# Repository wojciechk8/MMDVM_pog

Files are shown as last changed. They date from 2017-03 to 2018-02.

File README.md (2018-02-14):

This project is a hardware for the Multi-Mode Digital Voice Modem
([MMDVM](https://github.com/g4klx/MMDVM)). Instead of depending on
MCU development boards (like Arduino, STM Discovery, etc.), this design
contains a microcontroller itself, so no additional stuff is required.
This project is based on [SQ6POG](https://www.qrz.com/db/SQ6POG)'s idea,
and hence its name.

## Hardware 
The board contains STM32F105RBT MCU, two active low-pass filters: for
ADC and DAC. Additionally there is a place for an optional TCXO with
a buffer circuitry and LED indicators.

The PCB is prepared to be populated in two configurations listed below.
### Stand-alone
The board is populated with FT230XS USB-to-UART converter and 3.3V LDO

### As a Raspberry Pi HAT
This configuration is almost the same as previous, but with RPi
connector and without USB-to-UART converter and LDO.

## Building firmware
You can get the firmware from [MMDVM](https://github.com/g4klx/MMDVM)
github. The firmware can be built with the GNU ARM toolchain.
An additional requirement is the STM32CubeF1 package, which can be found
at STMicroelectronics website. Path to the CMSIS directory of
the extrected package should be adjusted in the Makefile.CMSIS as
CMSISDIR definition. Also uncomment these defines in the Config.h
file:
```
// For the SQ6POG board
#define STM32F1_POG
```
to enable MMDVM_pog board support,
```
// Pass RSSI information to the host
#define SEND_RSSI_DATA
```
to enable RSSI feature,
```
// Use pins to output the current mode
#define ARDUINO_MODE_PINS
```
to enable mode LEDs output,
```
// For 19.2 MHz
#define EXTERNAL_OSC 19200000
```
if you want to use external TCXO.

Be sure that defines regarding other boards are commented.

Finally to build the firmware simply run:
```
make -f Makefile.CMSIS
```

## Programming
### Via SWD
To program the device with SWD, run:
```
make -f Makefile.CMSIS program
```
(you will need *openocd* software and ST-LINK programmer).

### Via internal bootloader
If you don't have ST-LINK and want to use bootloader, then short JP1
jumper and run:
```
make -f Makefile.CMSIS program_bl
```
(you will need *stm32flash* software; serial port can be selected
in the Makefile)

## Hacking
### Schematic/PCB
This project was designed using *gEDA* software. In order to modify
the schematic you will need my library of symbols/footprints, which is
available [here](https://github.com/wojciechk8/geda-sym). The library
is also attached to this repository as a submodule (geda-sym). To get it
contents after cloning the repository run `git submodule update --init`.
Update of the PCB is done in the root directory with this command:
```
gsch2pcb mmdvm_pog.prj
```
Postscript and pdf export of PCB is done with:
```
./pcb_export mmdvm_pog.pcb
```

### Filter simulation
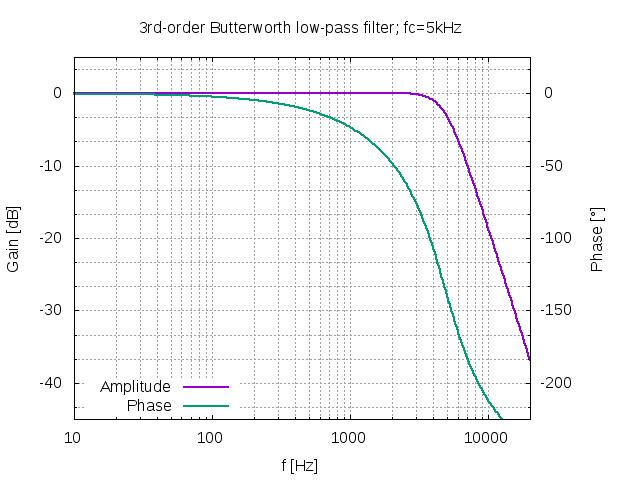
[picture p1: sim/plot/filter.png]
Filter frequency response simulation


The simulation of the filter (sim directory) was performed in *ngspice*
and the graphical plot output was generated using *gnuplot*. To run
the simulation use the script provided:
```
./simulate filter.sch
```

## License
This project is licensed under the CC-BY-NC-SA
(Creative Commons - Attribution, Noncommercial, Share Alike) license
and is intended for amateur and educational use only.

<p align="center">CC-BY-NC-SA</p>

MMDVM software is licenced under the GPL v2 and is intended for amateur
and educational use only. Use of this software for commercial purposes
is strictly forbidden.

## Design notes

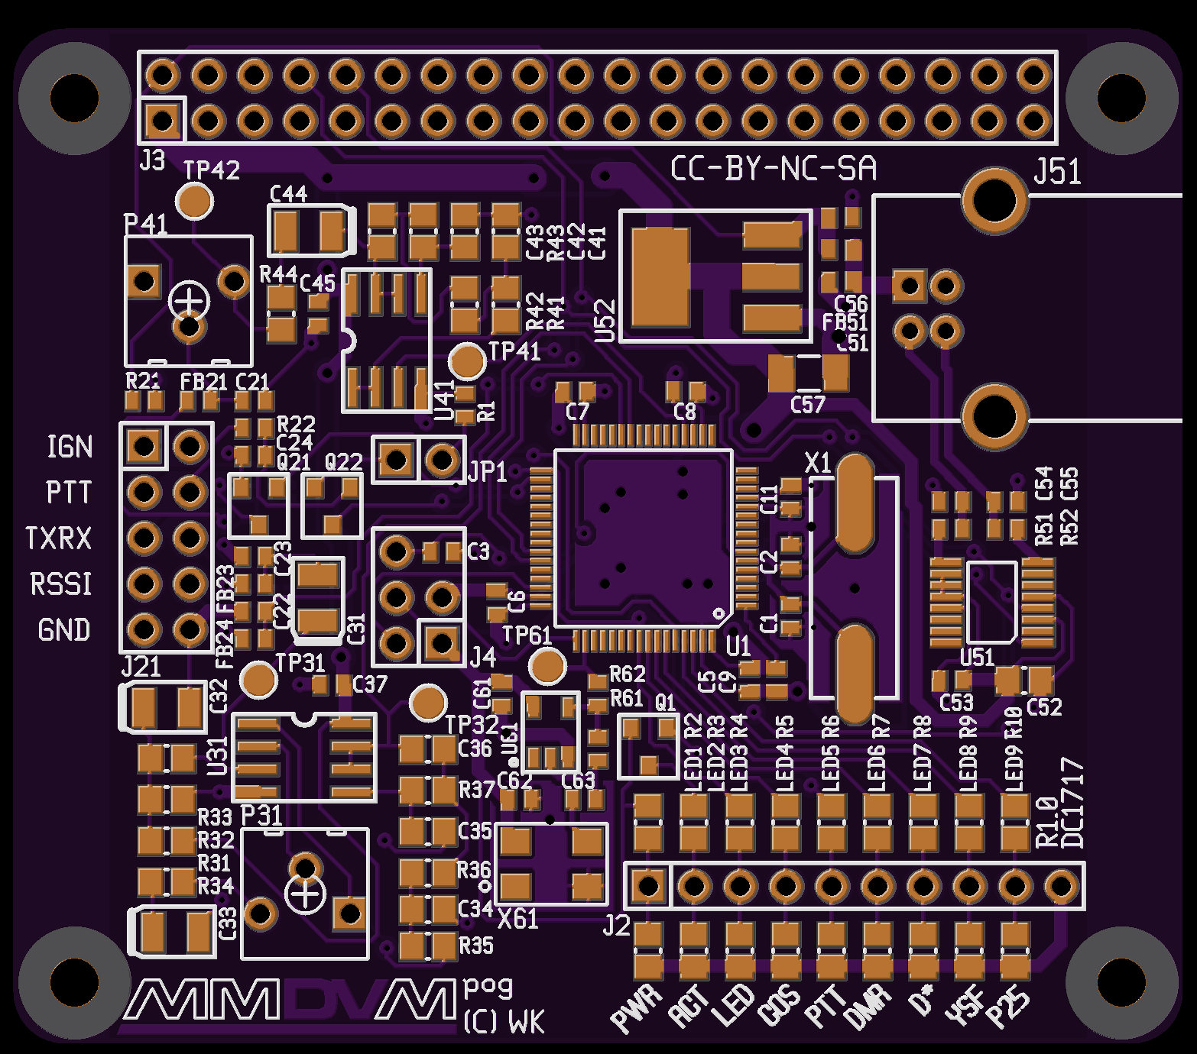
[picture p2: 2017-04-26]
pcb/mmdvm_pog.png

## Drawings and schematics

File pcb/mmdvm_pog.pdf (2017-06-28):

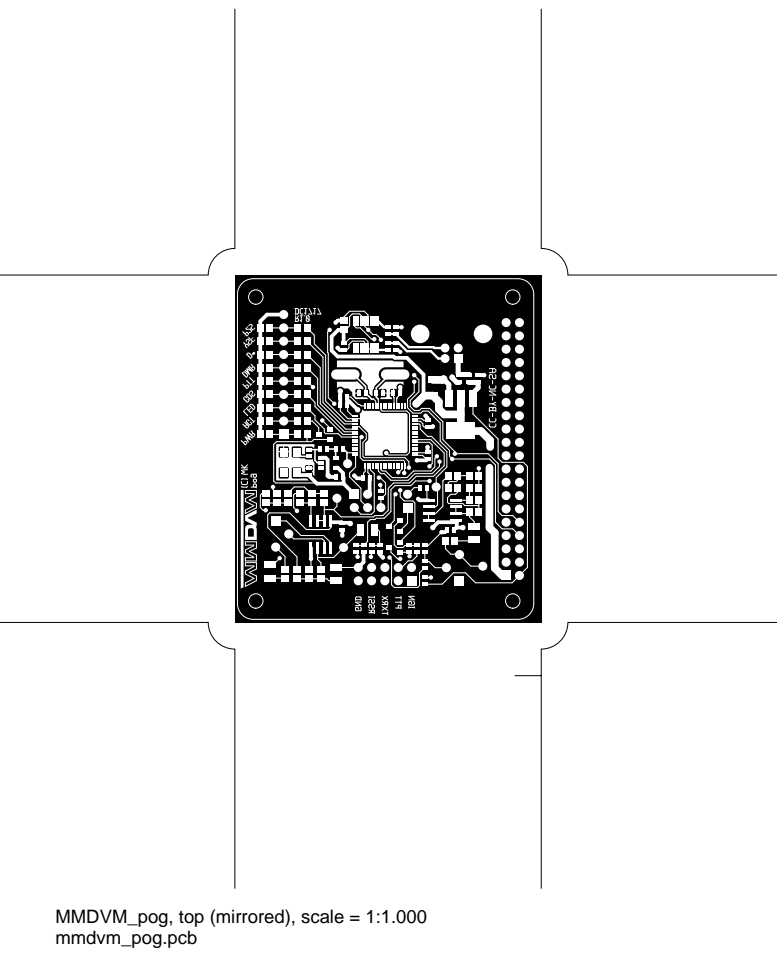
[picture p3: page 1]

MMDVM_pog, top (mirrored), scale = 1:1.000
mmdvm_pog.pcb

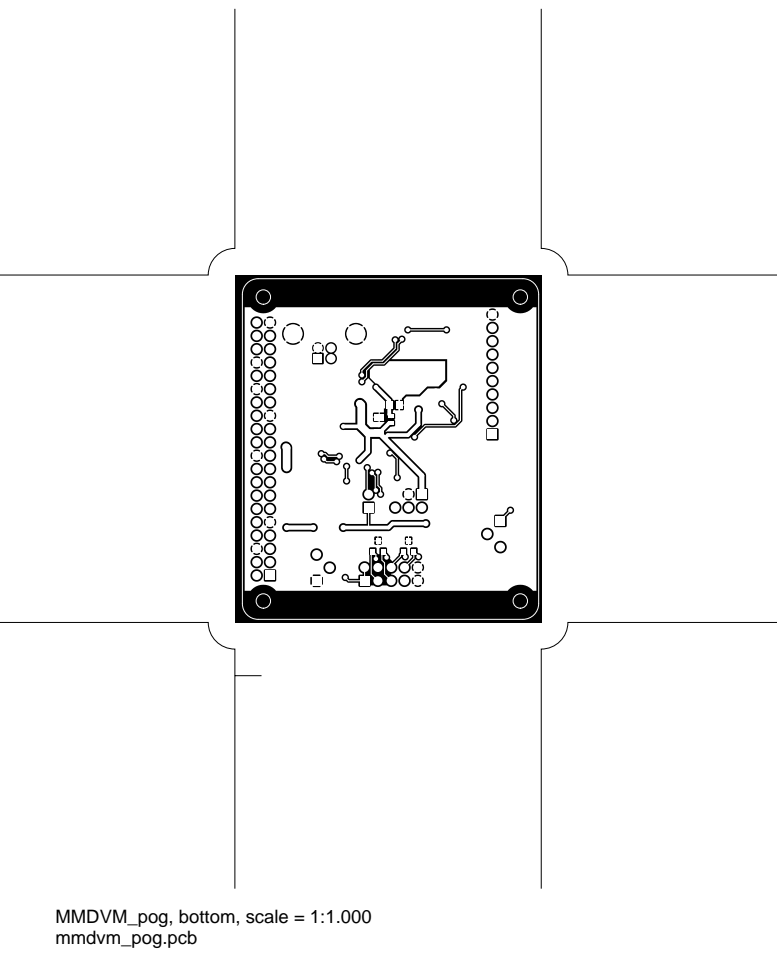
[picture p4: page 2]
MMDVM_pog, bottom, scale = 1:1.000

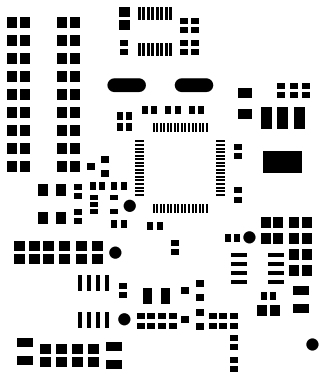
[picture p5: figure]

MMDVM_pog, toppaste (mirrored), scale = 1:1.000

MMDVM_pog, bottompaste, scale = 1:1.000

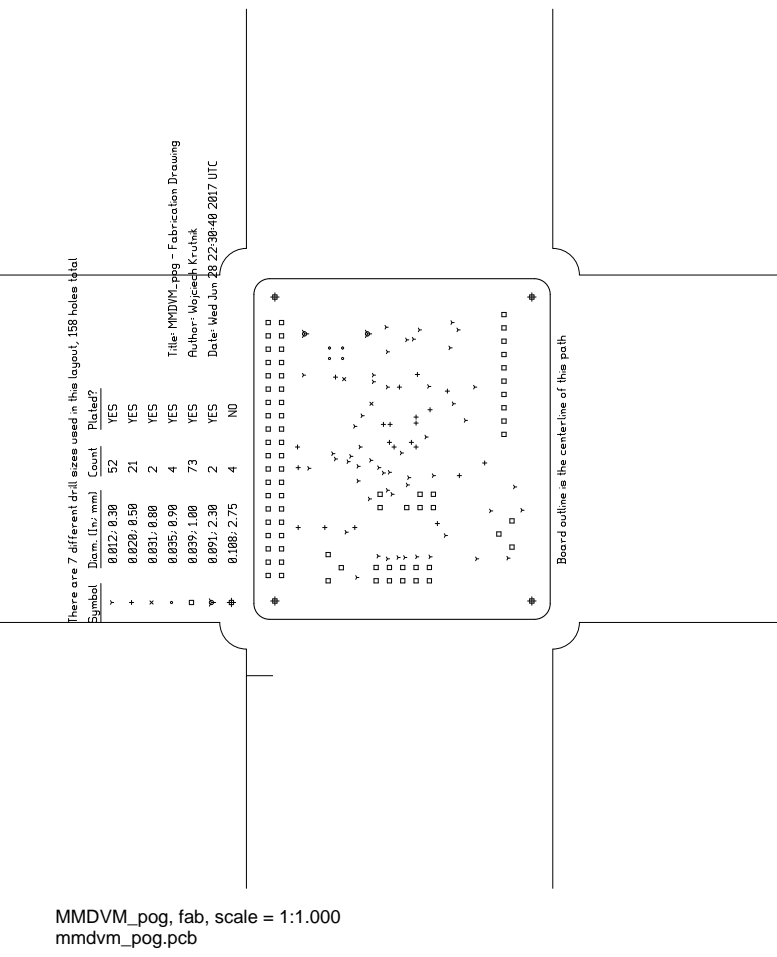
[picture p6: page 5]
MMDVM_pog, fab, scale = 1:1.000

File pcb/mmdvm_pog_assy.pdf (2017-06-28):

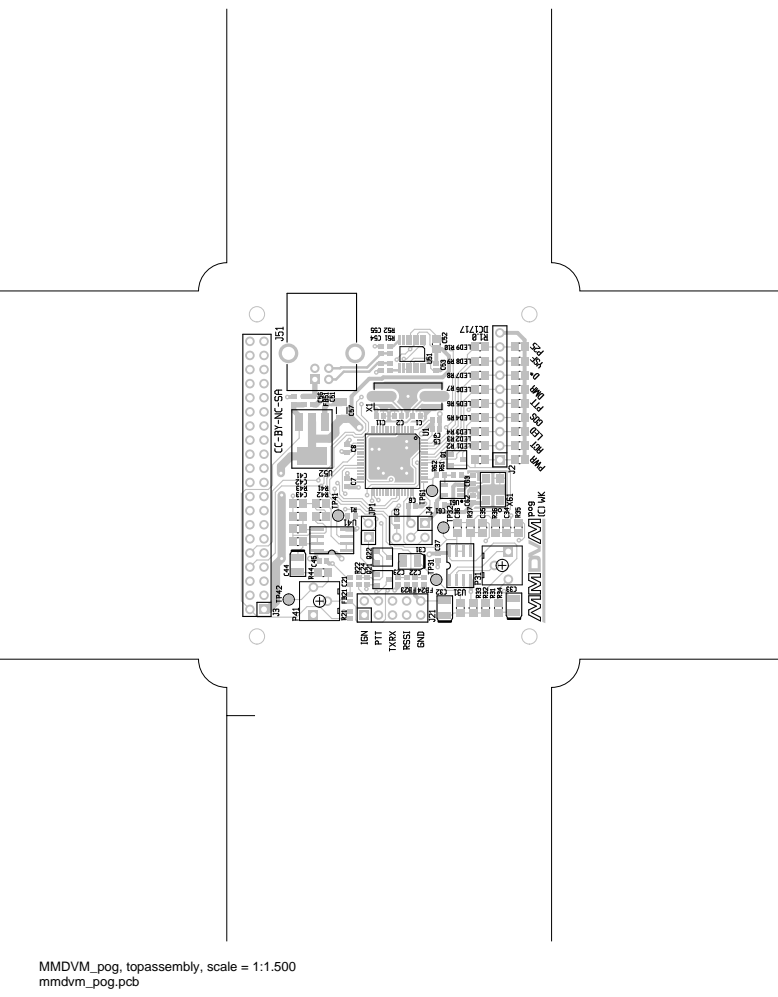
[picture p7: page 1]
mmdvm_pog.pcb; MMDVM_pog, topassembly, scale = 1:1.500

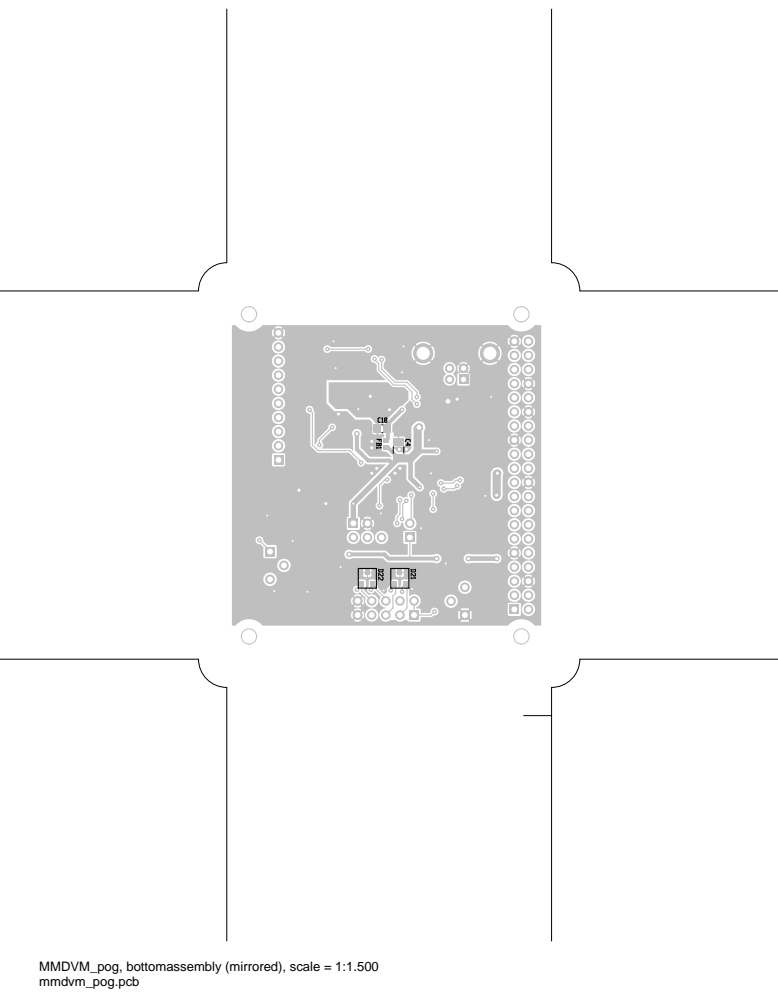
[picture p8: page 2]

MMDVM_pog, bottomassembly (mirrored), scale = 1:1.500
mmdvm_pog.pcb

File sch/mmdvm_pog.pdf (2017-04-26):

E

F

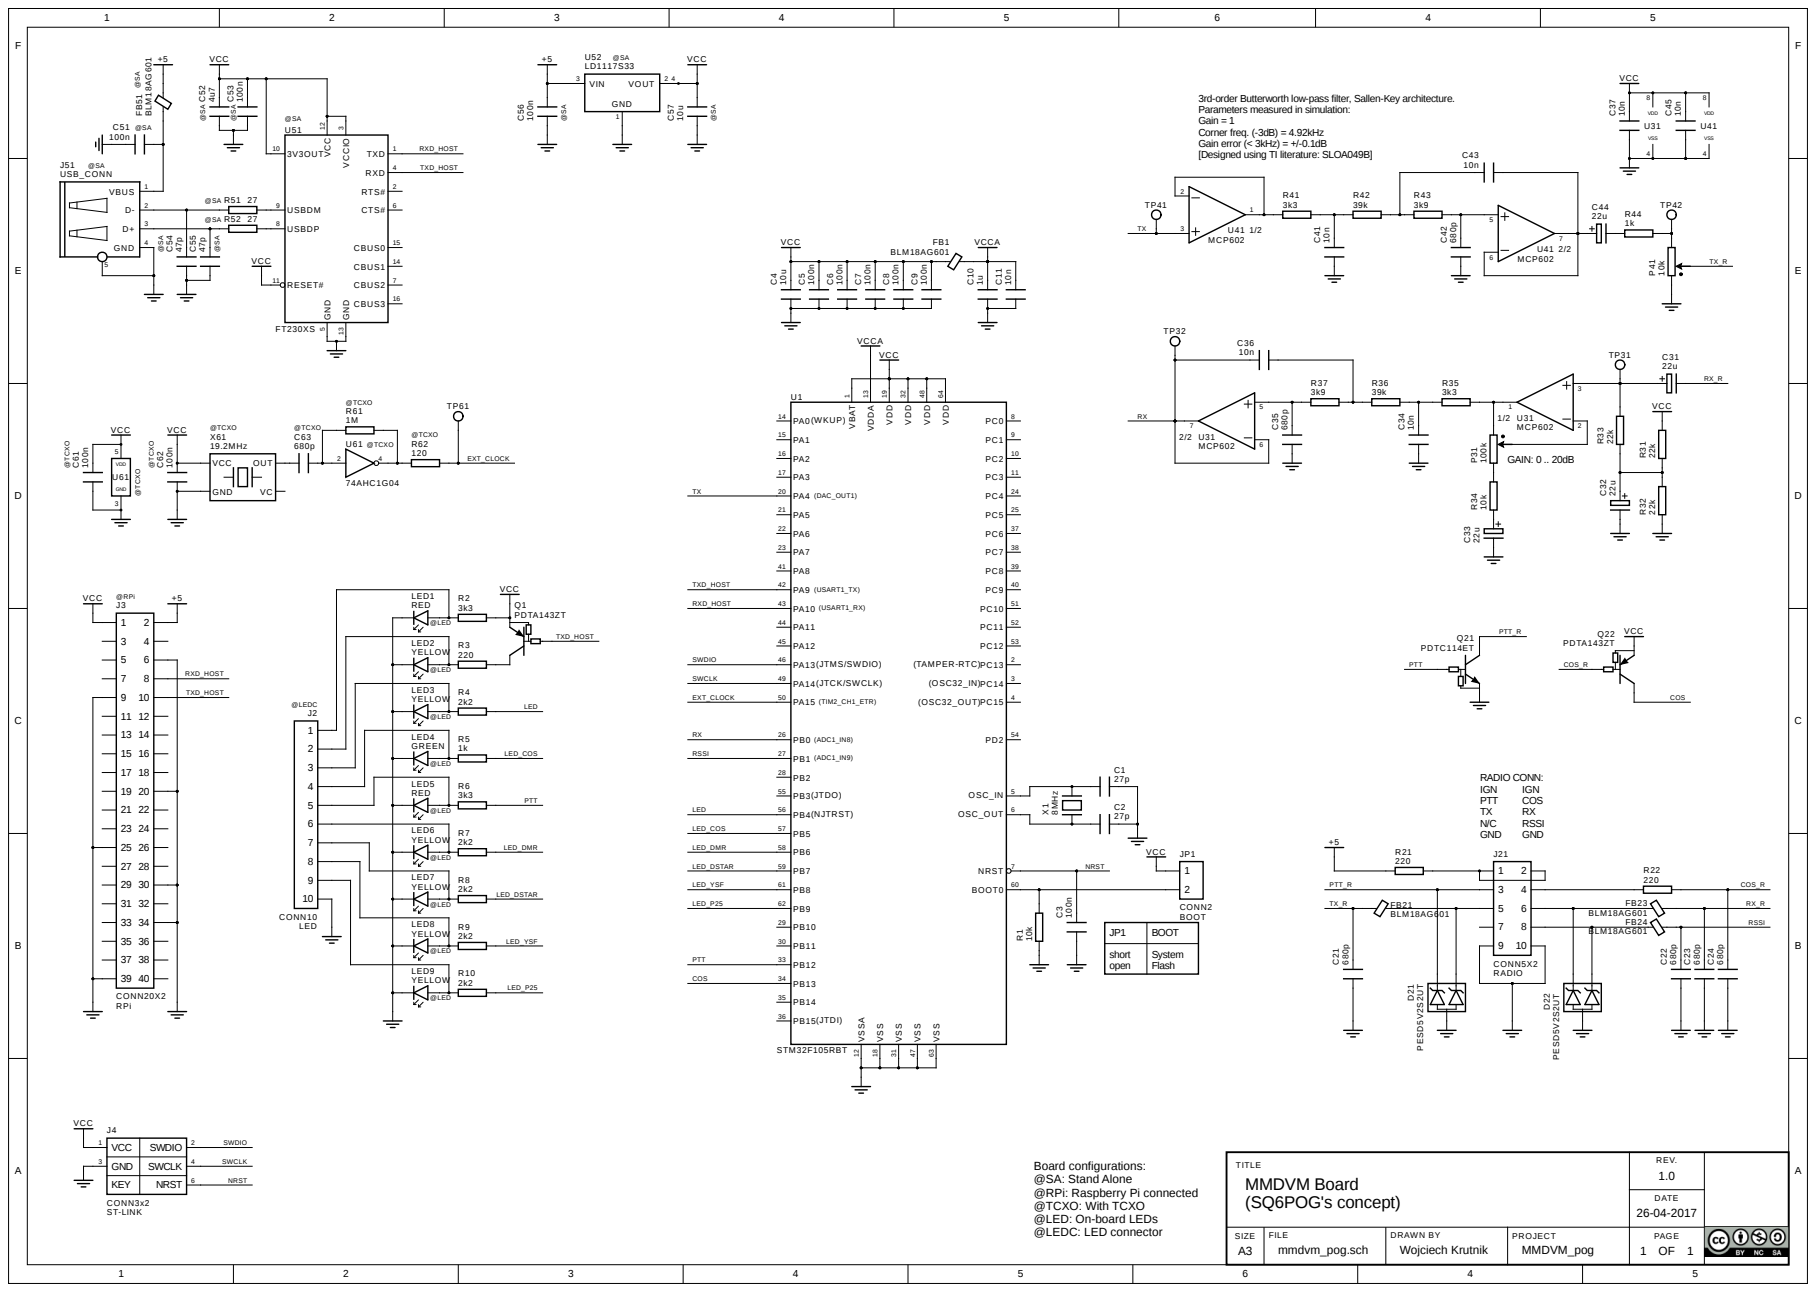
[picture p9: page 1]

3rd-order Butterworth low-pass filter, Sallen-Key architecture.
Parameters measured in simulation:
Gain = 1
Corner freq. (-3dB) = 4.92kHz
Gain error (< 3kHz) = +/-0.1dB
[Designed using TI literature: SLOA049B]

Board configurations:
@SA: Stand Alone
@RPi: Raspberry Pi connected
@TCXO: With TCXO
@LED: On-board LEDs
@LEDC: LED connector

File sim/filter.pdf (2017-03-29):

D
D

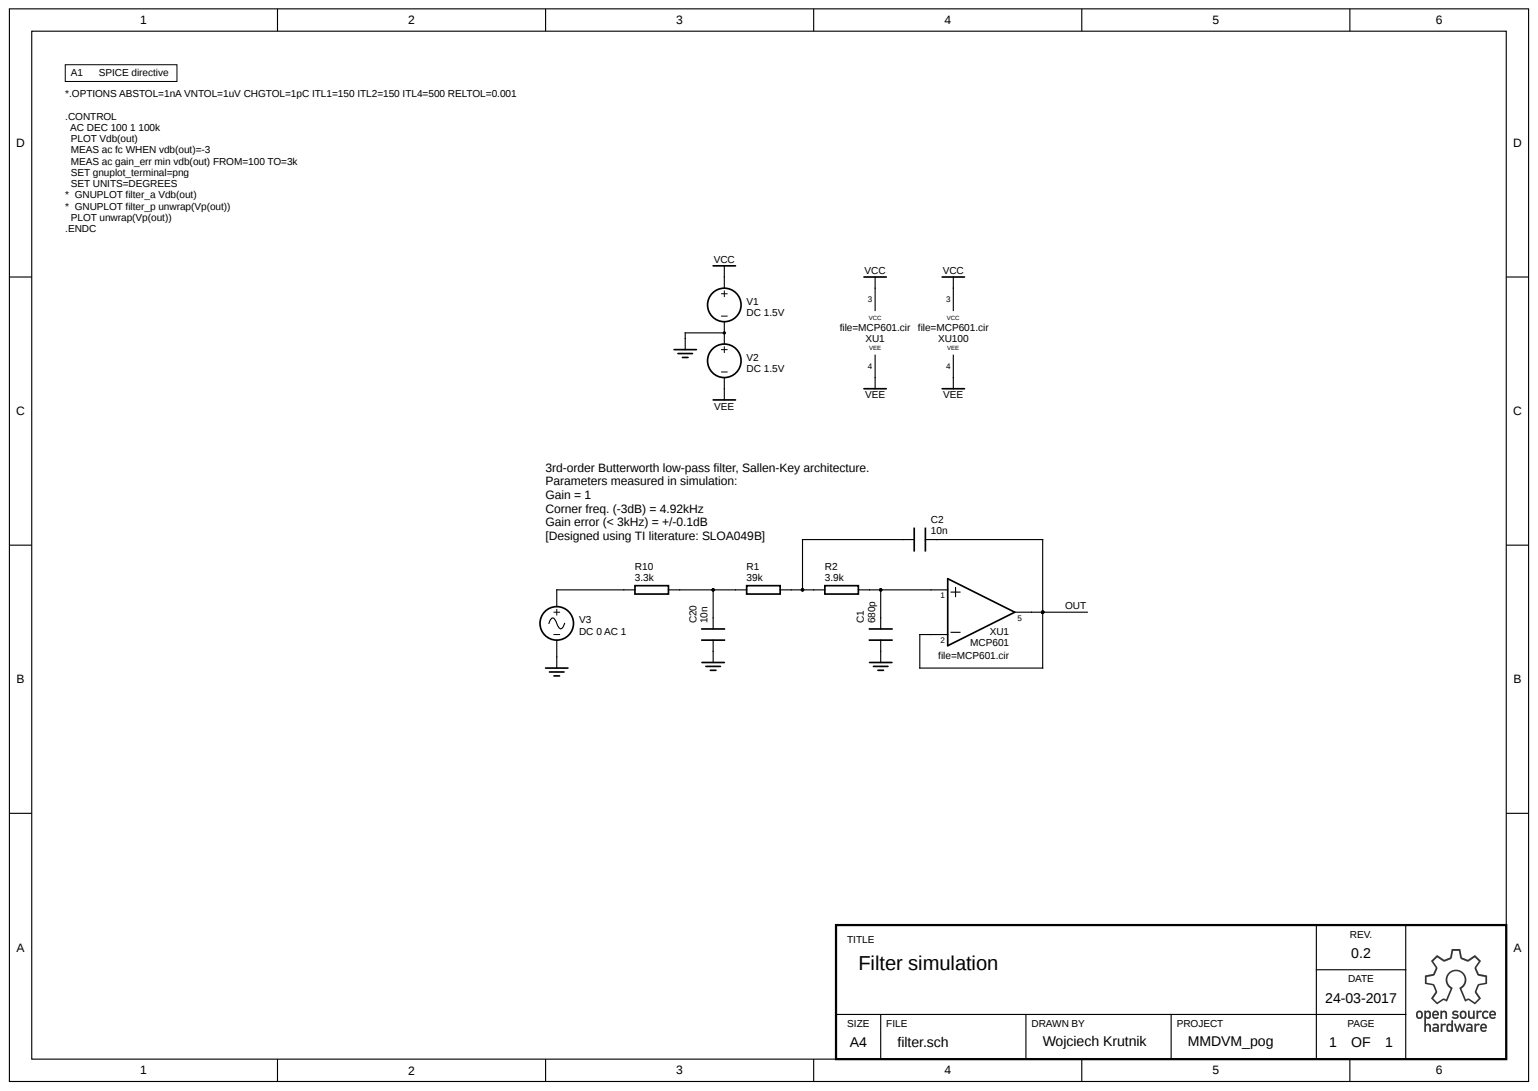
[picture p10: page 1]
FILE; REV.; DRAWN BY; PAGE; TITLE; PROJECT; DATE; SIZE A4; MMDVM_pog; Filter simulation; filter.sch; Wojciech Krutnik; XU1 MCP601 file=MCP601.cir; VCC; VEE; file=MCP601.cir; OUT; SPICE directiveA1

*.OPTIONS ABSTOL=1nA VNTOL=1uV CHGTOL=1pC ITL1=150 ITL2=150 ITL4=500 RELTOL=0.001

.CONTROL
AC DEC 100 1 100k
PLOT Vdb(out)
MEAS ac fc WHEN vdb(out)=-3
MEAS ac gain_err min vdb(out) FROM=100 TO=3k
SET gnuplot_terminal=png
SET UNITS=DEGREES
* GNUPLOT filter_a Vdb(out)
* GNUPLOT filter_p unwrap(Vp(out))
PLOT unwrap(Vp(out))
.ENDC

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

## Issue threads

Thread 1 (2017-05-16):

Move serial IO from pins 2 and 3 to 9 and 10

N4IRS, 2017-05-16:
I see you moved the communications port from PA2 and PA3 to PA9 and 10. I edited the IOSTM_CMSIS.cpp and changed 2 to 9 and 3 to 10. I can flash the LED, but I can not communicate with the processor. Did I miss something?

73, Steve N4IRS

wojciechk8, 2017-05-17:
Yes, I did it because previously I forgot to check which USART pins can be used to communicate with internal bootloader. Later it turned out that PA2, PA3 (USART2) couldn't be used for this purpose, so I changed them to PA9, PA10 (USART1). I suspect that you've changed only pins configuration in the IOSTM_CMSIS.cpp, but it's also required to change the actual USART in the SerialSTM_CMSIS.cpp. I've already done it and I'm attaching this file, but I haven't tested it yet. After I check if it works, I will do a pull request to the main MMDVM repository (now I'm waiting for ordered PCBs).

Regards
Wojciech

[USART1_fix.zip](https://github.com/wojciechk8/MMDVM_pog/files/1007351/USART1_fix.zip)

N4IRS, 2017-05-17:
Wojciech,
You are correct, I did try changing the pin numbers, but realized that the USART needed to be change. I just tried your changes. MMDVMHost still can not communicate with the processor. I am out of time for the next few days. When I get back I'll work with you to test and refine what is needed. Thank you again for your help.

73, Steve N4IRS

N4IRS, 2017-05-24:
Wojciech,
I put the CPU in BOOT_0 and reset the CPU. This is the result I get.
Interface serial_posix: 57600 8E1
Version      : 0x22
Option 1     : 0x00
Option 2     : 0x00
Device ID    : 0x0418 (STM32F105xx/F107xx)
- RAM        : 64KiB  (4096b reserved by bootloader)
- Flash      : 256KiB (size first sector: 2x2048)
- Option RAM : 16b
- System RAM : 18KiB
No doubt I can talk to the CPU via the USART in boot mode. I applied the code changes you posted. The compile but MMDVMHost can not communicate with the modem.
73, Steve N4IRS

wojciechk8, 2017-05-25:
Steve,
Maybe I missed something in USART configuration, I checked the firmware only with the previous PCB revision (on USART2). Now I have the new PCB, but the parts will arrive next week and then I'll test it and commit a fix.

wojciechk8, 2017-05-31:
Hi Steve,
I managed to run the firmware. There was a mistake in USART2Init function.
Instead of:
```
RCC->APB1ENR |= RCC_APB1ENR_USART2EN;
USART2->BRR = USART_BRR(36000000UL, speed);
```
it should be:
```
RCC->APB2ENR |= RCC_APB2ENR_USART1EN;
USART1->BRR = USART_BRR(72000000UL, speed);
```
I've already done a pull request to the main repository, so you should be able to pull the corrected code from there soon. Please check this on your hardware and tell me if there are any problems.

Regards
Wojciech

N4IRS, 2017-06-01:
Wojciech,
I applied your patches and I can now communicate with the MMDVM via the USART. Thanks! I will start testing using it with a radio in DMO this weekend. THANKS!
Steve

wojciechk8, 2017-06-01:
That's great!
I've just finished assembling 10 boards.
Paweł SQ6POG had tested them in duplex mode with Motorola GM340/350/950 and it worked great.

73 and good luck
Wojciech

Closed 2017-06-01.

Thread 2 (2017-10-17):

Compile error

applepeng, 2017-10-17:
/tmp/ccANnA6K.s: Assembler messages:
/tmp/ccANnA6K.s:461: Warning: ignoring changed section attributes for .data
/tmp/cc8vlPEj.s: Assembler messages:
/tmp/cc8vlPEj.s:17: Warning: ignoring changed section attributes for .data
/tmp/ccMkS9xt.ltrans0.ltrans.o: In function `process':
/home/pi/MMDVM/SerialPort.cpp:670: undefined reference to `CSerialPort::availabl                                                                                        eForWriteInt(unsigned char)'
collect2: error: ld returned 1 exit status
Makefile.CMSIS:145: recipe for target 'bin/mmdvm.elf' failed
make: *** [bin/mmdvm.elf] Error 1

wojciechk8, 2017-10-17:
Did you do all the steps described in "Building firmware"?
What is the command you're issuing to build the firmware?
I've just compiled the newest firmware without errors.

Regards
Wojciech

applepeng, 2017-10-17:
sudo make -f Makefile.CMSIS

N4IRS, 2017-10-17:
I just did a git clone of the MMDVM repository, added the STM32F4XX_Lib, edited Config.h and compiled with make -f Makefile.CMSIS. It compiled fine. I do have a script you can try that will setup the environment for you. it is at https://github.com/N4IRS/MMDVM-Install/tree/master/STM32-DVM. Maybe looking at the script can help you.

73, Steve N4IRS

applepeng, 2017-10-17:
Thank you！

73 ， BH7NJF

wojciechk8, 2017-10-17:
applepeng, the reason of compilation error was probably that you had enabled (uncommented) SERIAL_REPEATER option in config.h (it's not supported in MMDVM_pog board).

Regards,
Wojciech

Closed 2017-10-17.

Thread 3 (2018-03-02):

NXDN Led

s58DB, 2018-03-02:
Hello Wojciech, today I am looking your PCB board i like to build one but I have one suggestion. If you have time pleas add option for NXDN Led. I am look scheme in gEDA and this don't be problem to add.

Best regards, Danilo - S58DB

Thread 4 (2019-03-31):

Documentation ign pin

2E0PGS, 2019-03-31:
Hey great board however I cannot find out how the `IGN` pin is meant to be wired.

I see there is two ign pins that appear to be connected via trace however I don't know if this pin needs to be held low with ground, held high with 3.3v or held high with 5v.

If someone could clarify more detail on this it would be great.

I have figured out it's probably for car ignition? Because my PI wont boot with this hat ontop. I have to remove it before then add it once PI is booted which is not ideal.

Cheers,
2E0PGS

wojciechk8, 2019-04-11:
> Hey great board however I cannot find out how the IGN pin is meant to be wired.
Thanks! The IGN pin is constantly connected to +5V. It refers to Ignition Sense in Motorola radios, which is used to turn on/off the radio. An example of application: when MMDVM is powered through raspberry pi, then resetting rPI causes also radio reset.

2E0PGS, 2019-04-12:
Any idea as to why my PI doesn't boot with the hat on top then?

It boots I remove it and add it post network interface lighting up.

Thanks for info on what the pin is for though. That's still useful.

⁣Cheers,
2E0PGS

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

wojciechk8, 2019-04-12:
> Any idea as to why my PI doesn't boot with the hat on top then?

I don't know, maybe rPI is expecting a communication on USART during boot and it interferences with MMDVM.

Closed 2019-04-12.

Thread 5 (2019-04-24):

Not responding after 3mins continious transmitt

r7rbb, 2019-04-24:
In duplex mode after conttinious transmitting in local group( i mean not via internet)
recieving stops... and do not responding anymore and holds the carrier of the transmitter  until powered off!!
i occurs when transmitt over 2mins 30 sec

How to solve this issue?

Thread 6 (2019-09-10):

Unusable as is

yo6nam, 2019-09-10:
For a hobbyist this project is unusable. There are so many things and steps you need to make, apart from (installing VM, linux OS, readme steps), just to be able to export a copy of gerber files and BOM. I'm in the second day and still struggling with the current state of the files to make something that works or at least exports.
"gsch2pcb mmdvm_pog.prj" produces an error because there is no such thing as "partslist4"

Although I appreciate the author's efforts and the fact that it's been public since 2017, but it's funny to see this open source adapted (by some hams, china factories), modified and transformed into a commercial product and still, someone trying to get a PCB out of this hits so many problems.
If someone has knowledge with gEDA, please step in and make a few mods to this project :

- add a voltage divider (100K pot) for J21 pin 8 to STM32F105RBT pin 27
- add 2 connections from J3 pin 38 to STM32F105RBT pin 7 (NRST) and J3 pin 40 to STM32F105RBT pin 60 (BOOT0) to avoid this hack :
https://github.com/yo6nam/MMDVM_STMF1XX_FW/blob/master/pog_stm_update_mod.jpg
- (optional) P31 and P41 footprint changed. Parts will be replaced with :
https://www.tme.eu/en/details/t67w-10k/1-4-inch-multiturn-tht-trimmers/sr-passives/

N4IRS, 2019-09-10:
One thing you may want to consider is that STM32F105 is not fast enough to support all modes. It will do D-Star, DMR, YSF, P25 but not NXDN.

yo6nam, 2019-09-10:
Hi Steve,

We're not using P25 in my area so there's not much to lose. DMR and C4FM are the only modes that people in YO are using. I just want to build an improved version of this board and keep the costs low. Now that JLCPCB launched the SMT Assembly I could build a board for about 15 USD / pcs.

Regards and '73
Razvan / YO6NAM

k7ilo, 2023-04-11:
Yeah I know this is a old thread but I just wanted to know if there were any updates to this board or even the schematic files before i copy this schematic into later software and create newer gerber files.  JLCPCB will not except, or i think they wont except these versions of gerber.
Lucily, the parts list is here so i can make sure parts that were used for this design are still available.

But again, are there any updates around for this design?

Thanks

Harold
K7ILO

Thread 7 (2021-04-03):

HW / FW build and toolchain setup

nbgsmk, 2021-04-03:
Hello my friend!
I will try to build the MMDVM board with your gerber files and compile the firmware from source. There is a lot to learn in the process, and it's a nice challenge for (admittedly advanced) amateurs.
But ofcourse I ran into some difficulties (and anticipate others). So could you please help with a few things:
HW
- are your gerber files good for producing a pcb without any changes? I am thinking of a minimal quantity with JLCPCB and their smt assembly process.

FW
- what is the reason for choosing stm32f105 instead of 32f103c8 (like practically all others I can see online)
- what is your development environment: windows or linux?
- in file->preferences, what is the address in "additional board manager urls" ?
(After installing the board support according to some instructions on the net, I was able to build arduino due. But after installing the lib and switching to stm32f103, 105, 407, 411, they all fail with "unknown processor type". I followed g4klx's build instructions (many times:) ) but without success. Tried older versions of arduino ide, modified platform.txt etc..but the build still fails.)
In the latest attempt, the f105 cpu is not even available in the "board part number". I have only F103 variants, so I must be doing something wrong.
So, what goes here?
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

And what goes here?
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

- finally, do you compile from arduino ide -> sketch -> verify/compile or from the command line (and how exactly)?
- if you also tell me what is the modification in your platform.txt, I promise a big cold beer will be waiting for you in my fridge. :) :)

I am using the latest arduino ide 1.8.13 via installer.

Thanks!

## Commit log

2017-03-29 Removed unused vendor drill mapping file
2017-03-29 Exported pcb with drill sizes in millimeters
2017-03-29 Corrected simulation schematic
    [filter.sch]
2017-04-11 Corrected value of Q1
    [mmdvm_pog.sch]
2017-04-11 Changed position of license text on the pcb
2017-04-11 Combined multiple pcb_export outputs (top, bottom, fab) into one pdf
2017-04-12 Updated schematic pdf
2017-04-26 Changed host USART connection to pins PA9, PA10 (USART1), allowing for use the internal bootloader.
    [mmdvm_pog.sch]
2017-04-26 Changed value of R3 to 220 for brighter ACT LED
    [mmdvm_pog.sch]
2017-04-26 Updated PCB
2017-04-26 Changed location of testpoint TP41
    [mmdvm_pog.sch]
2017-04-26 Revision 1.0
    [mmdvm_pog.sch]
2017-04-26 Exported gerber files
    [mmdvm_pog.bottom.gbr, mmdvm_pog.bottommask.gbr, mmdvm_pog.bottompaste.gbr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]
2017-06-28 Update pcb_export script, add solder paste layer to output pdf
